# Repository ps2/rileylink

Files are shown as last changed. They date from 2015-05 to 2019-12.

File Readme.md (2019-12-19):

# RileyLink



A custom designed Bluetooth Smart (BLE) to Sub-1 GHz module. It can be used to bridge any BLE capable smartphone to the world of Sub-1 GHz devices. 

### Setup

 * There is a [FAQ](https://docs.google.com/document/d/1-KlewmRObpUWCTQSq9EPraN8R-6rCksJS_sRSQSexX0/edit#) covering some questions about installing the firmware.
 * [@loudnate](https://github.com/loudnate) recorded a [setup log](https://docs.google.com/document/d/1-bGBXbxVKOs_tDXi68qiOD7bIT6tQlkQydXn5Q-afLc/edit) of his experience.

### Hardware

See the [hardware](https://github.com/ps2/rileylink/tree/master/hardware) directory for design files to build a RileyLink. The hardware design is released under [Creative Commons Share-alike 3.0](http://creativecommons.org/licenses/by-sa/3.0/).  This board has small parts and will need to be reflow soldered; using a solder-paste stencil is recommended. 

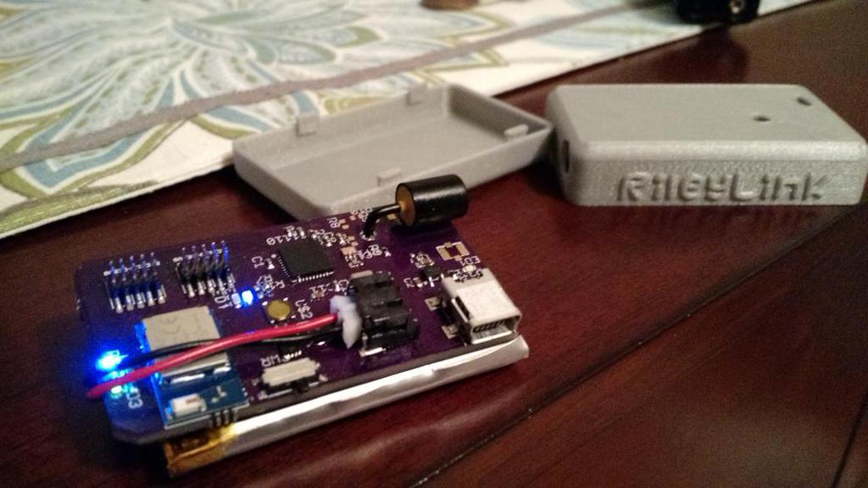
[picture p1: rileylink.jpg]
RileyLink Hardware


### Order a Pre-Assembed RileyLink
From time-to-time community members do a production run of pre-assembled RileyLink Boards. When they are available you can place an order here [GetRileyLink](https://getrileylink.org/)

### Firmware

The code in the [firmware](https://github.com/ps2/rileylink/tree/master/firmware) directory runs on the RileyLink hardware.  There are two main chips on the RileyLink, and thus two firmware images.

### LED Lights

There are blue and green leds near both chips. The ble113 is on the upper right of the board, and the cc1110 is in the lower middle.  

Blue for the ble113 indicates there are packets received and ready for a phone to pick up. Green means the phone is connected to the ble113.

On the cc1110, I blue is a timer based on/off, letting you know the firmware code is running. Green is toggled when a packet comes in.

The other red LED indicates charging.

### License

The MIT License (MIT)

Copyright (c) 2015 Pete Schwamb

Permission is hereby granted, free of charge, to any person obtaining a copy
of this software and associated documentation files (the "Software"), to deal
in the Software without restriction, including without limitation the rights
to use, copy, modify, merge, publish, distribute, sublicense, and/or sell
copies of the Software, and to permit persons to whom the Software is
furnished to do so, subject to the following conditions:

The above copyright notice and this permission notice shall be included in all
copies or substantial portions of the Software.

THE SOFTWARE IS PROVIDED "AS IS", WITHOUT WARRANTY OF ANY KIND, EXPRESS OR
IMPLIED, INCLUDING BUT NOT LIMITED TO THE WARRANTIES OF MERCHANTABILITY,
FITNESS FOR A PARTICULAR PURPOSE AND NONINFRINGEMENT. IN NO EVENT SHALL THE
AUTHORS OR COPYRIGHT HOLDERS BE LIABLE FOR ANY CLAIM, DAMAGES OR OTHER
LIABILITY, WHETHER IN AN ACTION OF CONTRACT, TORT OR OTHERWISE, ARISING FROM,
OUT OF OR IN CONNECTION WITH THE SOFTWARE OR THE USE OR OTHER DEALINGS IN THE
SOFTWARE.

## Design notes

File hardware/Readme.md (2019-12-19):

# RileyLink Hardware

 * board.sch - circuit schematic
 * board.brd - pcb design file
 * bom.csv - materials list
 * case_bottom.stl - 3d printer model for case bottom
 * case_top.stl - 3d printer model for case top

### Order the PCB from OSH Park:

[RileyLink v1.0](https://oshpark.com/shared_projects/jWrg6WmU)

### Components

The bom.csv file contains a list of parts and quantities along with their Digikey part number.

### PCB Assembly

A stencil for the PCB can be obtained at a reasonable price from [OSH Stencils](https://www.oshstencils.com).  Just upload the .brd file and accept the default mappings.

You will have to look at the schematic and the PCB PDFs or open them in [Eagle](http://www.cadsoftusa.com/) to know where the parts go, and how they are oriented.

I use a hot-air rework station to flow the solder paste, but you could use a toaster oven setup as well.

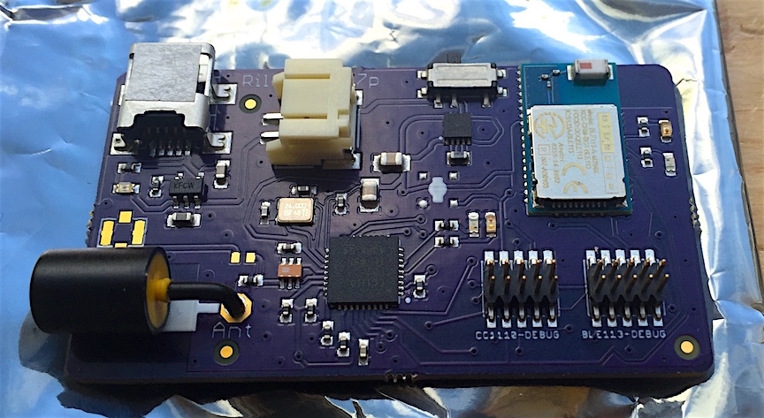
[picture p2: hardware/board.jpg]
Assembled Board


### Case

I created a case using [Tinkercad](https://www.tinkercad.com), a great tool.

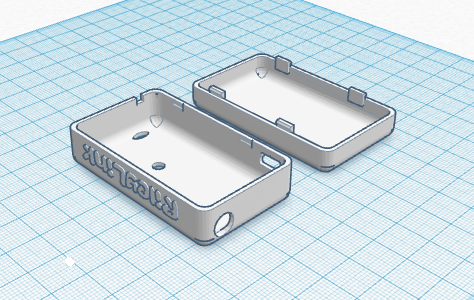
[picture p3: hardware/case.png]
3D Printed Case


The case is designed to hold an [850mAh Lipo](https://getrileylink.org/product/850lionbattery/). That battery lasts a day or so when the RileyLink is constant listen mode. It should last longer if the firmware uses a duty cycle that's less than 100%.

### Fitting components inside case

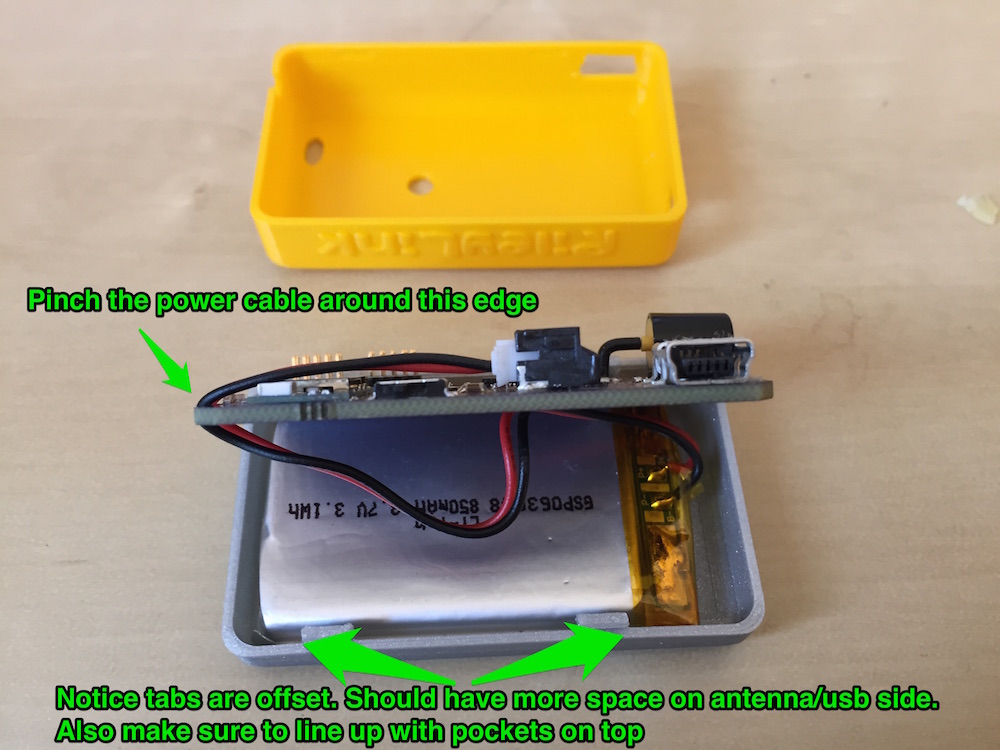
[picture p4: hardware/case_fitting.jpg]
Case Fitting


Note: there’s an issue I have with the case that I haven’t fixed yet; the board in the case can rotate a bit so that the usb port doesn’t line up with the hole. If stick a small something (like those sticky pads that keep cabinet doors from slamming) to the top of the usb port, that fixes the issue.

### 868MHz (EU) version

Since the firmware allows changing of the frequency, and most people are using the 915Mhz antenna successfully with 868Mhz pumps, a custom RileyLink is not needed.

### License

The hardware design is released under [Creative Commons Share-alike 3.0](http://creativecommons.org/licenses/by-sa/3.0/).

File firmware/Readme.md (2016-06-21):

# Loading Firmware

There are two microprocessors on the RileyLink board; a ble113 module, and a cc1110. Each needs it's own firmware.

## CC1110 Firmware

For the cc1110, you should install the latest [subg_rfspy](https://github.com/ps2/subg_rfspy) firmware.

- Use spi1_alt2_RILEYLINK_US_STDLOC.hex if you are in the USA/Australasia
- Use spi1_alt2_RILEYLINK_WW_STDLOC.hex if you are elsewhere (the pump serial printed
    on the back of the device will end with 'WW' if you need to use this)

## BLE113 Bluetooth Module

For the ble113, you should install the firmware in the ble113_rfspy subdirectory.
Using the BLE Update tool (details below).

1. Install the Bluetooth Firmware Update and the Bluetooth SDK tools as per the "Prerequisites" section below.
2. Install SmartRF Studio as below, so that you have USB drivers for the CC-Debugger.
3. Go to https://github.com/ps2/rileylink and click the "Clone or download" option.
4. Select "Download ZIP"
5. Extract the Zip in your download directory.
6. Double click on the Project file in the ble113_rfspy folder.
7. If you receive the message "Unable to automatically select BGBuild":
  - Click BGBuild menu item, and choose "Manually Select"
  - Choose My Computer -> C: -> Bluegiga -> blue-1.4.2-130 (or similar) -> bin -> bgbuild

## Disabling Bluetooth

If you want to completely disable the bluetooth part of the RileyLink, you can use the
'ble113_disabled' firmware. This is normally only done when you are using the RileyLink
over serial, using it as a mmeowlink radio.

## Prerequisites

## CC1110 Firmware

If you can, use a pre-built firmware from subg_rfspy release list on GitHub. You can then
use the following tools to write the firmware:

* For Windows: [cc-debugger](http://www.ti.com/tool/cc-debugger)
* For Linux: cc-tool. See [cc-tool](https://github.com/oskarpearson/mmeowlink/wiki/Firmware-install-with-CC-Tool-%28Linux%29) for instructions on installation and usage.

### Bluetooth Firmware

Windows machine (or VM) with:

* SmartRF Studio - tested with 2.3.1 from http://www.ti.com/tool/smartrftm-studio (Make sure to 'Extract All' if prompted at install/unzip time)
* "BLE Update Tool v1.3.6 (Windows XP,7,8 and 10)" (or above) **AND** "Bluetooth Smart Software and SDK v.1.4.2" applications
from the [ble113 product page](https://www.bluegiga.com/en-US/products/software-bluegiga-bluetooth-smart/)

Note that you will need to sign up for an accounts to download both installers.

## Troubleshooting

- If you receive the message "CebalChip Object has no attribute Reset" when writing
  bluetooth firmware, then check that you've not accidentally plugged into the
  CC1110 port. Also check that you've connected the CC-Debugger correctly.

## Connecting the CC Debugger to the RileyLink

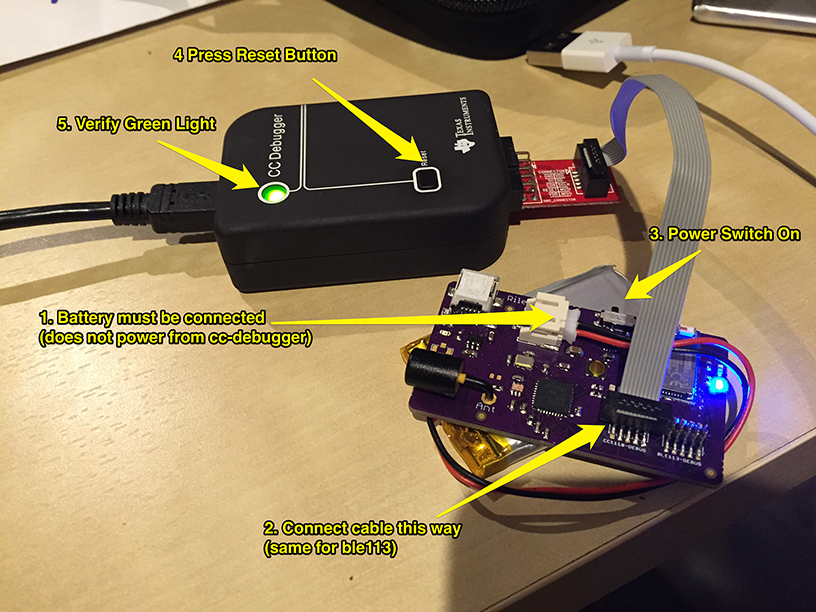
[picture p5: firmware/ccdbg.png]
cc-debugger connection illustration


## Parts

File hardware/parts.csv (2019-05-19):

Part | Description | Digi-Key Part Number
ANT1 | Antenna 916MHZ | ANT-916-JJB-RA-ND
BLE113-DEBUG | CC-Debugger Header | 609-3695-1-ND
C1 | 0.10µF ±10% 10V X5R Capacitor 0402 | 587-1227-1-ND
C2 | 4.7µF ±10% 10V X5R Capacitor 0603 | 445-7482-1-ND
C3 | 4.7µF ±10% 10V X5R Capacitor 0603 | 445-7482-1-ND
C4 | 10µF ±10% 6.3V X5R Capacitor 0805 | 1276-6457-1-ND
C5 | 12pF ±1% 50V C0G, NP0 Capacitor 0402 | 490-6196-1-ND
C6 | 12pF ±1% 50V C0G, NP0 Capacitor 0402 | 490-6196-1-ND
C7 | 0.10µF ±10% 10V X5R Capacitor 0402 | 587-1227-1-ND
C8 | 0.10µF ±10% 10V X5R Capacitor 0402 | 587-1227-1-ND
C9 | 1µF ±10% 6.3V X5R Capacitor 0402 | 399-4873-1-ND
C10 | 0.10µF ±10% 10V X5R Capacitor 0402 | 587-1227-1-ND
C11 | 10µF ±10% 6.3V X5R Capacitor 0805 | 1276-6457-1-ND
C12 | 0.10µF ±10% 10V X5R Capacitor 0402 | 587-1227-1-ND
C13 | 0.10µF ±10% 10V X5R Capacitor 0402 | 587-1227-1-ND
C14 | 4.7µF ±10% 10V X5R Capacitor 0603 | 445-7482-1-ND
CC1110 | CC1110 SOC RF Transceiver | 296-38560-1-ND
CC1110-DEBUG | CC-Debugger Header | 609-3695-1-ND
IC1 | 915 MHz Impedance Matched Balun-Filter | 712-1541-1-ND
JP1 | 2 Positions JST Header 2mm | 455-1749-1-ND
L1 | 2.2µH Shielded Wirewound Inductor 1.46A | SRN3010-2R2MCT-ND
LED1 | LED RED CLEAR 0603 SMD | 160-1447-1-ND
LED2 | LED BLUE 0603 SMD | 350-4381-1-ND
LED3 | LED GREEN CLEAR 0603 SMD | 511-1299-1-ND
LED4 | LED GREEN CLEAR 0603 SMD | 511-1299-1-ND
LED5 | LED BLUE 0603 SMD | 350-4381-1-ND
PWR | SWITCH SLIDE SPDT 300MA 6V | 401-2016-1-ND
R1 | 2k Ohm ±5% 0.063W, 1/16W Resistor 0402 | 311-2.0KJRCT-ND
R2 | 330 Ohm ±5% 0.063W, 1/16W Resistor 0402 | 311-330JRCT-ND
R3 | 56k Ohm ±1% 0.063W, 1/16W Resistor 0402 | 311-56.0KLRCT-ND
R7 | 470 Ohm ±1% 0.063W, 1/16W Resistor 0402 | 311-470LRCT-ND
R9 | 0.0 Ohm Jumper 0.063W, 1/16W Resistor 0402 | 311-0.0JRCT-ND
R11 | 470 Ohm ±1% 0.063W, 1/16W Resistor 0402 | 311-470LRCT-ND
R12 | 470 Ohm ±1% 0.063W, 1/16W Resistor 0402 | 311-470LRCT-ND
R13 | 470 Ohm ±1% 0.063W, 1/16W Resistor 0402 | 311-470LRCT-ND
U1 | L-ION Battery Management IC | MCP73831T-2DCI/OTCT-ND
VREG | 3.3V Buck Converter 0.6A SOT23 | LM3671MF-3.3/NOPBCT-ND
U3 | Bluetooth Low Energy BLE113-A 256K | 1446-1035-1-ND
X1 | 24MHz ±15ppm Crystal 8pF 50 Ohm | 644-1052-1-ND
X3 | USB - mini B USB 2.0 Receptacle Connector | H2959CT-ND

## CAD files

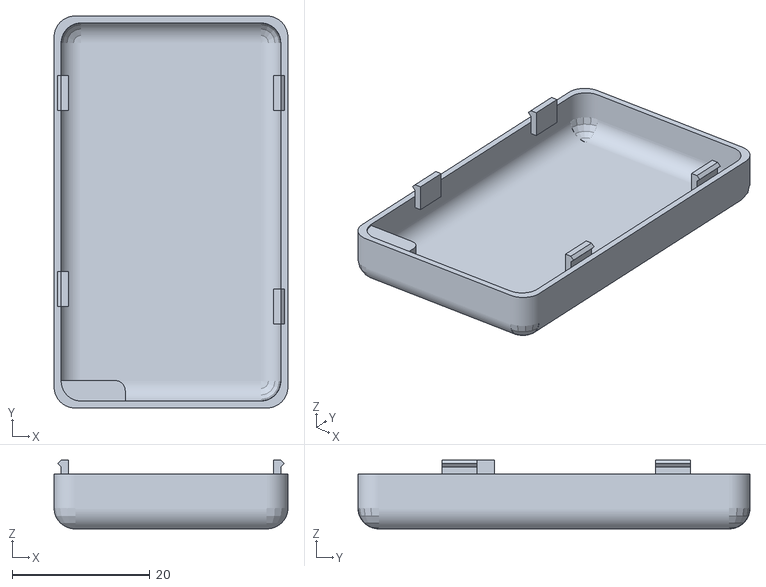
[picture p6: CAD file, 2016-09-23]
hardware/case_bottom_edit.stl
34.0 x 57.0 x 10.0

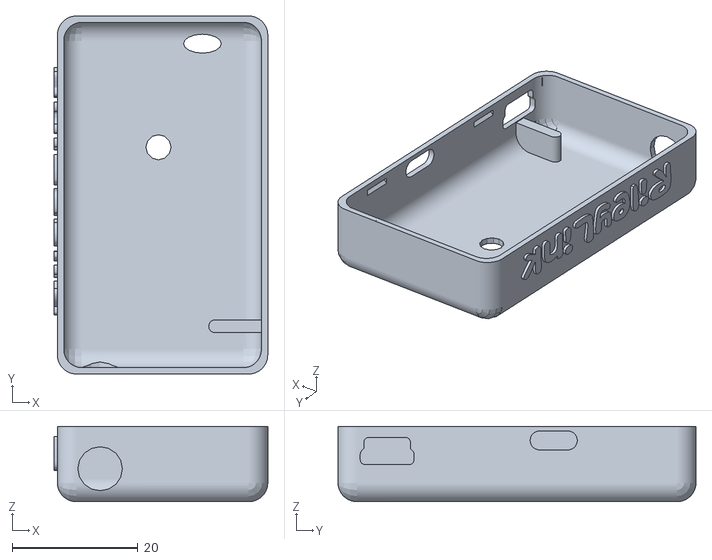
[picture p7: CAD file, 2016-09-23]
hardware/case_top_edit.stl
34.0 x 57.0 x 12.0

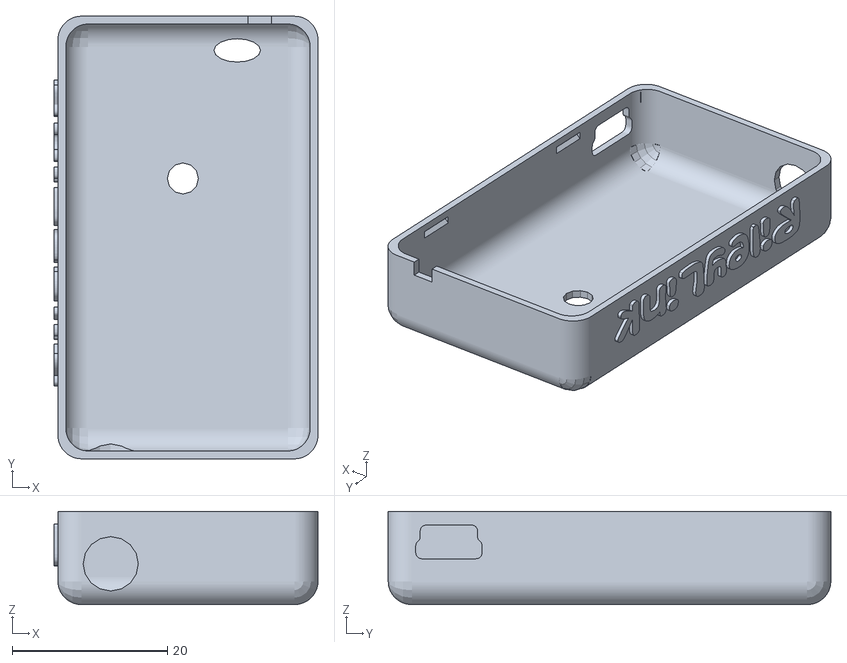
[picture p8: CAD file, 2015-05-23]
hardware/case_top.stl
34.0 x 57.0 x 12.0

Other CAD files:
hardware/case_bottom.stl

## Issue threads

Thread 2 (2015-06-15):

bigger ble pads

ps2, 2015-06-15:
bluetooth board part in eagle needs to be a bit bigger. Extend the pads out a little. Probably 1mm on the left and right side. This will allow hand soldering and better smt soldering with no bubbles

ps2, 2016-07-26:
after having RL's produced at professional shops with no issues here, I think we'll leave them as is.

Closed 2016-07-26.

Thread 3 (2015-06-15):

update switch

ps2, 2015-06-15:
Switch should be fixed also it's a little off.

ps2, 2015-08-23:
I'm not sure exactly what this refers to. Jason made a comment, and I recorded this ticket, but afaik, the switch works fine.

Closed 2015-08-23.

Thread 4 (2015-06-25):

add bluetooth device serial # to guarantee binding to unique device.

ps2, 2015-06-25:

ps2, 2015-08-17:
The app now remembers bluetooth device ids, and lets the user specify which ones to connect to.

Closed 2015-08-17.

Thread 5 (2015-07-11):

button

AtomSoftTech, 2015-07-11:
Remove reset

Closed 2017-03-10.

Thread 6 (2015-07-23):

app: feature to configure pump as mysentry broadcast (pair)

ps2, 2015-07-23:
MySentry has the user put the pump into a discovery mode, where it broadcasts packets including the pump id.  The MySentry sends a response with its own id, which the pump then adds to its list of devices it accepts queries from. The pump also then starts broadcasting pump status messages every five minutes.

The screen should walk the user through this process, using a paired RileyLink, and display status updates as it receives packets from the pump and verifies it can talk to the pump.

loudnate, 2015-07-23:
Have you captured the packet that needs to be sent back?

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

ps2, 2015-07-23:
I believe the packets involved have these types:

https://github.com/ps2/minimed_rf/blob/master/lib/minimed_rf/messages/message_type_map.rb#L10-L11

I'll see if I can find full examples in my packet log.

ps2, 2015-07-23:
It looks like this:

a2 AAAAAA 0a BB CCCCCC DD EE

AAAAAA = pump id
BB = ? (my example had 8f)
CCCCCC = mysentry id (mine was 000695)
DD = ? (my example had 01)
EE = crc

loudnate, 2015-07-30:
Will the RileyLink capture the pump's broadcast packets during discovery mode? I lack a lot of understanding in how the actual IC Rx/Tx flows work, but I'm eager to figure this out.

ps2, 2015-07-30:
Yes, the Rileylink will listen for the pump's message, since it has the pump ID in it, and that way the user doesn't have to enter it in.

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

loudnate, 2015-08-10:
Have you started this feature? I can take a stab at it this week since I'm going to have to go through this process anyway with my rig.

ps2, 2015-08-10:
I haven't started it quite yet; I am working on the packet sending code, so this particular area is in a bit of flux. I think I'm close, though.  Feel free to start if you want; just be warned that the sending code in RileyLinkBLEDevice is changing.

loudnate, 2015-08-12:
What's the significance of "0a" in the MySentry discovery confirmation packet?

Here's the packet format sent by the pump in "Find Device" mode:
`a2 594040 09 BB 999999 00 EE`

BB increments, usually as a single counter, which keeps the CRC (EE) changing, but the byte prior is always 09. Does 09 signify a discovery while 0a signifies a confirmation?

ps2, 2015-08-12:
That's my take on it as well: https://github.com/ps2/minimed_rf/blob/master/lib/minimed_rf/messages/message_type_map.rb#L10-L11

loudnate, 2015-08-12:
I played with this for a bit but didn't have any luck pairing yet. Any idea on the frequency and repetitiveness of the link messages?

The `BB` sequence in the pump message is a counter that increments by 1, though it sometimes repeats in the same second. It's not time-based, though: if you exit the Find Device mode and start over, it will pick up where it left off. I wonder if it needs to be replayed in the link message?

loudnate, 2015-08-14:
From @ps2: https://gist.github.com/ps2/f80ff7a400bcecfd9479

loudnate, 2015-08-14:
Here's what worked for me:
```objc
@interface MySentryPairingViewController () {
    unsigned char _messageCounter;
}

- (void)viewDidLoad {
    [super viewDidLoad];
    [self.device setTXChannel:3];
    _messageCounter = 0;
}

- (NSString *)mySentryReplyForPacket:(MinimedPacket *)p
{
    static NSString *MySentryID = @"000888";

    NSString *packetStr = [@"a2" stringByAppendingFormat:@"%@%02x%02x%@00%02x000000",
                           [[Config sharedInstance] pumpID],
                           MESSAGE_TYPE_PUMP_STATUS_ACK,
                           messageCounter++,
                           MySentryID,
                           p.messageType];

    return packetStr;
}
```

It's possible to replay multiple messageTypes in a single `06` packet, and @ps2's paring log shows this, but I simply replied immediately during my spoofing.

Closed 2015-08-15.

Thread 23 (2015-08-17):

Send ACK for all `a2` packets

loudnate, 2015-08-17:
Should we keep track of paired MySentry IDs, then?

loudnate, 2015-08-17:
Pete suggested we don't have to worry about "real" MySentry devices, and of course we'd only ACK for the Pump IDs we know about.

ps2, 2015-08-18:
This issue was moved to ps2/rileylink_ios#2

Closed 2015-08-18.

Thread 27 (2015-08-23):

unique id

ps2, 2015-08-23:
Expose a unique id as an attribute, based off of the internal unique bluetooth id.

https://bluegiga.zendesk.com/entries/72030216--HOW-TO-Get-a-BLE-peripheral-MAC-address-with-iOS-and-CoreBluetooth

This id can be used for traceability, to determine what happened after issues occur.

Closed 2017-03-10.

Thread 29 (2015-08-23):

semver for cc1110 firmware

ps2, 2015-08-23:
This should also be made visible as a bluetooth attribute

ehwest, 2016-01-23:
Can you please document somewhere exactly how the RF modem used for the Nightscout project relates to the cc1110 firmware properties?  How did you select the requisite header file values?

ps2, 2016-01-23:
Not sure what you're asking here.  This ticket is about letting users know which version of firmware they currently have installed on their device.

The gitter channel (https://gitter.im/ps2/rileylink) is a good place to ask general questions about this project.

ps2, 2016-07-26:
We have firmware version reporting from subg_rfspy now.

Closed 2016-07-26.

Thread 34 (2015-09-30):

Mouser Project for UK/UE Rileylink

oskarpearson, 2015-09-30:
Hi

Attached is a Mouser project with enough components to make about 5 UK/EU Rilelylinks with a bunch of the cheap components spare (enough to lose / burn out / keep for later)

Note - it will _not_ work in the USA as I've changed the Balun and Antenna as described at https://github.com/ps2/rileylink/tree/master/hardware#868mhz-eu-version

I'm not 100% sure the components are all correct yet - but if they are, it should ease ordering for other people, since they don't have to select from 27,000+ capacitor models.. Feedback on my selections is welcome. My one concern is it seems some of the capacitors in the diagram are electrolytic - but I couldn't find electrolytic capacitors in those ranges. I also had to switch the LEDs, as I couldn't find the model referenced.

http://www.mouser.com/ProjectManager/ProjectDetail.aspx?AccessID=2316caefe4

Once I know this works, I'll submit a PR and update the BOM

Oskar

ps2, 2015-09-30:
Thanks Oskar!

I built a list at digikey using the same components that I've used to build my own RileyLinks.  Might want to compare the capacitors and resistors.  There are only a few that require tight tolerances.  The led resistors and power filtering caps just have to be ballpark.

https://www.digikey.com/classic/RegisteredUser/BOMBillOfMaterials.aspx?path=1&exist=1&id=2957565

This list also has "extra" parts for the 0402 size pieces, as those are super easy to lose.  Sometimes the extra amount is 10+, since it's cheaper to buy 10 than it is to buy 2 or 3.

Closed 2017-03-10.

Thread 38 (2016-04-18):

Use pump TZ instead of local TZ for parsing events.

ps2, 2016-04-18:
Primary issues in NightscoutUploadKit

loudnate, 2016-04-18:
There's a couple of interesting things here.

1. History parsing always needs to start from page 0 so no time change events are missed.
2. More than one time change record can occur during a pass-through history, so there's a concept of a mutable time zone during the reverse-walk.

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

Closed 2017-03-10.

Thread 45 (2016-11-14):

Provide battery voltage

trixing, 2016-11-14:
It would be great to have a way to ask rileylink for the voltage of the internal battery to alert users when it needs to be charged.  Not sure if that's possible with the current hardware or would need some changes?

trixing, 2017-01-13:
Most notable  P0_7 - P0_0 are connected to the ADC, so a voltage divider of VBAT to any of these would do the trick.

ps2, 2017-01-13:
Yes, I've looked at doing a vdiv, but decided that would be constantly draining power (though I haven't done the work to figure out how low I can make that leak and still measure accurately).

So I designed a version that used a mosfet to turn on and off a vdiv measuring circuit, but I had issues with my prototypes (must've screwed up something). At that point I decided I'd sunk too much energy into the issue.

For me, the main goal here is to minimize the effort users have to spend on maintaining charge on the RL.  Nightly charging is the simplest method, in my opinion.  I'd rather have a habit that I don't think about than have to look at battery status routinely. I'd even take a nightly charge over a 4 or five day charge.

Back when android phones had way worse battery life than iPhones (they've both moved in directions that make them more comparable now), I had an android and my wife had an iPhone.  I was forced into nightly charging, whereas she could go several days w/o charge.  Guess who had more annoying impacts due to running out of power at inconvenient times?

So, this issue has been thought through (maybe too much).  As usual, I'd love PRs that are a result of tested prototypes.  Otherwise this kind of report is usually just idle speculation from a back-seat designer. ;)

trixing, 2017-01-13:
Typically you would use a 10k / 10k Ohm divisor, which would put current at 3.7V / 20000 = 0.185mA.  Given that this is a 850mAh battery it would only affect the battery life very minimally.

Do you actually know what is drawing so much power to drain the 850 mAh that quickly?

ps2, 2017-01-13:
Yes, I think my original idea to save power with a mosfet was probably overkill, but after spending all that time on it, and realizing that it wouldn't make much of a difference in my use of the device, I decided not to spend more time chasing after it. Again, feel free to work on an updated design, test it, and submit a PR.  As in software, idle comments on how things can be improved without actual contribution can be irritating to the people that work through all the details of actual implementation.  In hardware it's even worse, as the cycles are so long.

Regarding your second comment, are you referring to the regulator issue?  If so, please move that comment over there.

Closed 2017-01-13.

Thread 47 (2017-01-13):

The voltage converter design should follow recommendations from the datasheet

trixing, 2017-01-13:
http://www.ti.com/lit/ds/symlink/tps63031.pdf #11.2

in particular the placement of the capacitors could be better.

Also I wonder how the induction coil was chosen?  It seems to be 7x the internal resistance than the recommended types in the datasheet (0.7 Ohm vs. 0.1 Ohm or less).

(I have a problem with the tps chip getting really hot, but still keeping voltage - I'm theorizing there is some stray capacitance/inductance with some bad feedback. Everything else works.)

ps2, 2017-01-13:
I've gone through several versions of the design that follow the datasheet layout and component selection more closely, and have still been having issues.

Check out the https://github.com/ps2/rileylink/tree/v1.0t branch, for the latest.

ps2, 2017-01-13:
Actually, the v1.0t is using a completely different regulator.  Check out v0.8test2 for previous versions that use the same regulator but follow the datasheet very strictly.

trixing, 2017-01-13:
I'm surprised that still causes issues - what kind of issues if I might ask?  Did you consider just using a 3.3V LDO?

ps2, 2017-01-13:
Same issues of overheating, drawing 200mA.  Yes, looked at 3.3V ldo; wanted a more efficient design, so the new one is a buck.

trixing, 2017-01-26:
I just tried this.  I have a Rileylink which pulls 300mA from the Lipo constantly.  To test if the regulator is broken I directly connecting 3.3V _after_ the regulator.  This lead to a power draw of 0.02A and a working communication with the pump.

Next step I put in a LM1117-3.3V (bad choice but the only one I had around, drop-out of 1V, thus 3.1V at the CC1110).  With a voltage of 5V applied at the input side my current draw is also only 0.02A.  The efficiency seems to be similar and the Rileylink is working again.

I have to get a LDO with less drop-out voltage, otherwise I can only get around 20-30% capacity out of the battery.  Luckily there is a bunch of alternatives and I just ordered an LP2992 which supposedly only has around 0.1V drop voltage.

(As background I can recommend reading

http://electronics.stackexchange.com/questions/38782/regulated-3-3v-from-a-lithium-ion-or-lipo-battery )

Closed 2017-03-10.

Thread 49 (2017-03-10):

Power failure

jessicakarma, 2017-03-10:
Hi, I've using RileyLink and Loop since 1/20/2017.  In the past few days Loop has not been connecting (indicated by red circle) and I realized that RileyLink is not holding a charge.  Starting today it doesn't appear to be working at all, even when plugged in.

I saw there is an update coming.  Question:  Do I need to buy another one, or will a replacement be sent automatically?  If I buy another, of course I'd like to have the new version.

Thanks!

ps2, 2017-03-10:
The green light is not a power light. It's a bluetooth connection light. Have you tried diagnosing your bluetooth connection?  Try restarting the Loop app, and bluetooth on the phone, and see if the green light comes on.

Also, check your battery connector to make sure it's seated all the way in (on some rileylinks this can be a very tight fit).

jessicakarma, 2017-03-10:
Hi Pete, thanks much for your quick reply!

I’ve been restarting both the Loop app and the phone; sometimes this works but unfortunately not today.  Other bluetooth devices continue to work including Dexcom G5, so I take it the issue is with the RileyLink connection?

I also opened RileyLink and set the battery and connector i proper place.  Al components are sung and seem to be where intended.

Any other suggestions?

Love Loop, and a big part of that is the streamlined equipment made possible by you!  Many, many thanks for this!! :-)

Take care,
Jessica

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

ps2, 2017-03-10:
Send me a DM on gitter or facebook, and I'll see if we can get you a replacement.

Closed 2017-03-10.

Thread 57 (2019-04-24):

Parts list

javaboyjunior, 2019-04-24:
Hi there

4 of the parts in bom.csv are obsolete on Digikey.com. I have been in touch with Digikey and they have provided part numbers for replacement products. Will you accept a pull request for an updated bom.csv and confirm the specs of the 4 new parts if I make the edit?

Thanks

Mike

xs10shl, 2019-04-30:
Second the request. I'm getting the same Digi-Key errors, and would like to piggyback on the homework already done by javaboyjunior.

Also, If there's an alternate part number for the Omnipod antenna, perhaps that could be added as well. I see a few choices for the 433mhz antenna, none of which look exactly ghe same as the version you used.  ANT-433-HESM-ND appears to be the closest.

javaboyjunior, 2019-04-30:
Here's my list including replacement parts as recommended by Digikey Tech Support.

[bomupdatedmike.csv.zip](https://github.com/ps2/rileylink/files/3130036/bomupdatedmike.csv.zip)

xs10shl, 2019-04-30:
Thx much, I'll put eyes on it tomorrow as well.

stephenclong, 2019-05-19:
The parts list looks like it's specific to the Medtronic version?  Can someone who knows way more about this than me provide details of which parts I need to switch out to make it work for the Omnipod?  Is it the same PCB?

javaboyjunior, 2019-05-19:
I asked in the support channel and was told the Parts are the same other
than the antenna. I used this for the antenna...

DAOKI 10pcs 433MHz antenna...
https://www.amazon.com/dp/B01CGMOYYM?ref=ppx_pop_mob_ap_share

On Sat, May 18, 2019 at 8:59 PM stephenclong <notifications@github.com>
wrote:

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

ps2, 2019-05-19:
Yes the parts on the 433 MHz RL right now are the same as 915 MHz.  But we use this antenna: https://www.ebay.com/itm/10Pcs-433MHz-Helical-antenna-High-quality-Useful-with-Good-Quality/323119548775

ps2, 2019-05-19:
Looked over your replacements, and they look good @javaboyjunior. Thanks!

Closed 2019-05-19.

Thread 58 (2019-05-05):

R9 - where is it?

javaboyjunior, 2019-05-05:
I can find R9 on the PCB, silk screen or in Eagle but it is on the parts list. What am I missing? Thanks!

javaboyjunior, 2019-05-08:
Thanks!

Closed 2019-05-08.

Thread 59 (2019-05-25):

Now I have found R9...

javaboyjunior, 2019-05-25:
I see R4 is right above it but not listed in the parts list. I am building a 433Mhz board. Anything to be done here? Thank you

ps2, 2019-05-25:
R4 is just a place to put a 0-ohm resistor if you want to hook up the u.fl connector.

javaboyjunior, 2019-05-25:
Thank you

On Sat, May 25, 2019 at 3:17 PM Pete Schwamb <notifications@github.com>
wrote:

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

Closed 2019-05-25.

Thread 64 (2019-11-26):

Antenna 433MHz for omnipod rileylink in parts list

jbayart, 2019-11-26:
For the omnipod rileylink, it is a 433 MHz antenna but there is no branch omnipod where the antenna is replaced in the csv in the hardware folder. I am not sure which antenna is used to build the riley.

breakery, 2019-11-26:
Not sure if I get your question right: still a simple helical antenna is used such as this one https://www.amazon.com/433MHz-Antenna-Control-Intercom-Helical/dp/B06Y691H5T

jbayart, 2019-11-26:
Yes I will probably use one like this. But I would like the exact same antenna like the other antenna with the digikey part number to be sure the dimensions fit with the case.

ps2, 2019-11-26:
There isn't a digikey part for this. These are the same part: https://www.ebay.com/itm/10Pcs-433MHz-Helical-antenna-High-quality-Useful-with-Good-Quality/323119548775

jbayart, 2019-11-26:
great, thanks !

larsvandoremalen, 2020-02-03:
Just to check, the ebay seller indicated does not ship to NL (almost nowhere in europe) and I read somewhere that the antenna signal quality has a lot of influence on creating screamers, would any of the digikey components below be good enough as well?

https://www.digikey.nl/product-detail/nl/pulselarsen-antennas/W3127/553-1696-ND/2538463
https://www.digikey.nl/product-detail/nl/linx-technologies-inc/ANT-433-HESM/ANT-433-HESM-ND/413457
https://www.digikey.nl/product-detail/nl/linx-technologies-inc/ANT-433-HETH/ANT-433-HETH-ND/625468

There is also an [aliexpress product](https://www.aliexpress.com/item/32962433768.html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,searchweb201602_4,searchweb201603_53) with a very low VSWR. But not certain if that makes it any better than the digikey ones.

First time posting, only just got started on building a loop. Want to do as much by myself as possible to fully understand the system. Thanks a lot for all the hard work that went into that!

breakery, 2020-02-04:
The aliexpress looks fine. Have a look here as well: https://www.amazon.de/dp/B00SO651VU/ref=cm_sw_em_r_mt_dp_U_N8roEb6AJERDF

Those are simple and tested. Range up to approx. 10m.

larsvandoremalen, 2020-02-05:
Thanks! Afraid even the amazon.de one does not ship to the Netherlands. They normally do but for components it's still a bit of hit and miss. Will try the aliexpress one then, thanks for the help.

breakery, 2020-02-05:
If urgent I can send one from de -> nl.

larsvandoremalen, 2020-02-05:
No urgency at all luckily, only preparing to start looping in March/April when I have everything ready. Good to now buy these components with some spare parts already :) Very nice of you to offer though, thanks!

breakery, 2020-02-05:
otherwise have a look here if you want to have some casing and inductive charging: https://sugarloop.makery.de/

ps2, 2020-02-05:
@breakery We have been testing out various designs of inductive charging, water resistant cases for the [official RileyLink site](https://getrileylink.org/), and we have one that is working *very* well; better than any of the others I've seen. It's going to be injection molded, so it's taking a little while to get the tooling set up.

Closed 2019-11-26.

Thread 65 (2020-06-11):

BOM for 433 Mhz version

konovagit, 2020-06-11:
Hi Pete,

I have a question concerning the 433 MHz version. Do you have a bom.csv for this version ?

OtherwiseI just have to change the antenna and the balun, right? I see this version https://getrileylink.org/product/rileylink433 so if you have the component ref it will be great.

Thank you for your job :)

jaredkzr, 2020-10-13:
I'm curious about this as well. The 433 MHz version purchased from https://getrileylink.org/product/rileylink433 appears to have the 915 MHz balun installed which would cause a reduction in range. I can't confirm this though since we have no BOM for the 433 MHz version.

It does appear that changing the antenna and balun is all that is necessary as far as the hardware is concerned. The CC1110 transceiver will have to be configured for 433 MHz though.

hansdampf01, 2020-10-22:
just found this issue: https://github.com/ps2/rileylink/issues/57 where the same question was asked and Im also facing it.
It seems like the antenna module of the 915mhz version will be need you just replace the actual antenna. e.g. to this:

https://www.amazon.de/gp/product/B07QGQ1VG5/ref=crt_ewc_title_huc_1?ie=UTF8&psc=1&smid=A3BN2T8LLIRB5S

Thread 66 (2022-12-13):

I have trouble with the rileylink

henrycoding, 2022-12-13:
Thank you very much for such open-source project. I'm going to follow your steps to make my own rileylink, but the pump doesn't respond in time. I'd like to debug the link between the CC1110 and my pump, but it seems the protocol of Medtronic 722 is not available on the Internet. So I wonder if there are some basic commands I can send to the pump to test the wireless link ?  Thanks a lot !!!

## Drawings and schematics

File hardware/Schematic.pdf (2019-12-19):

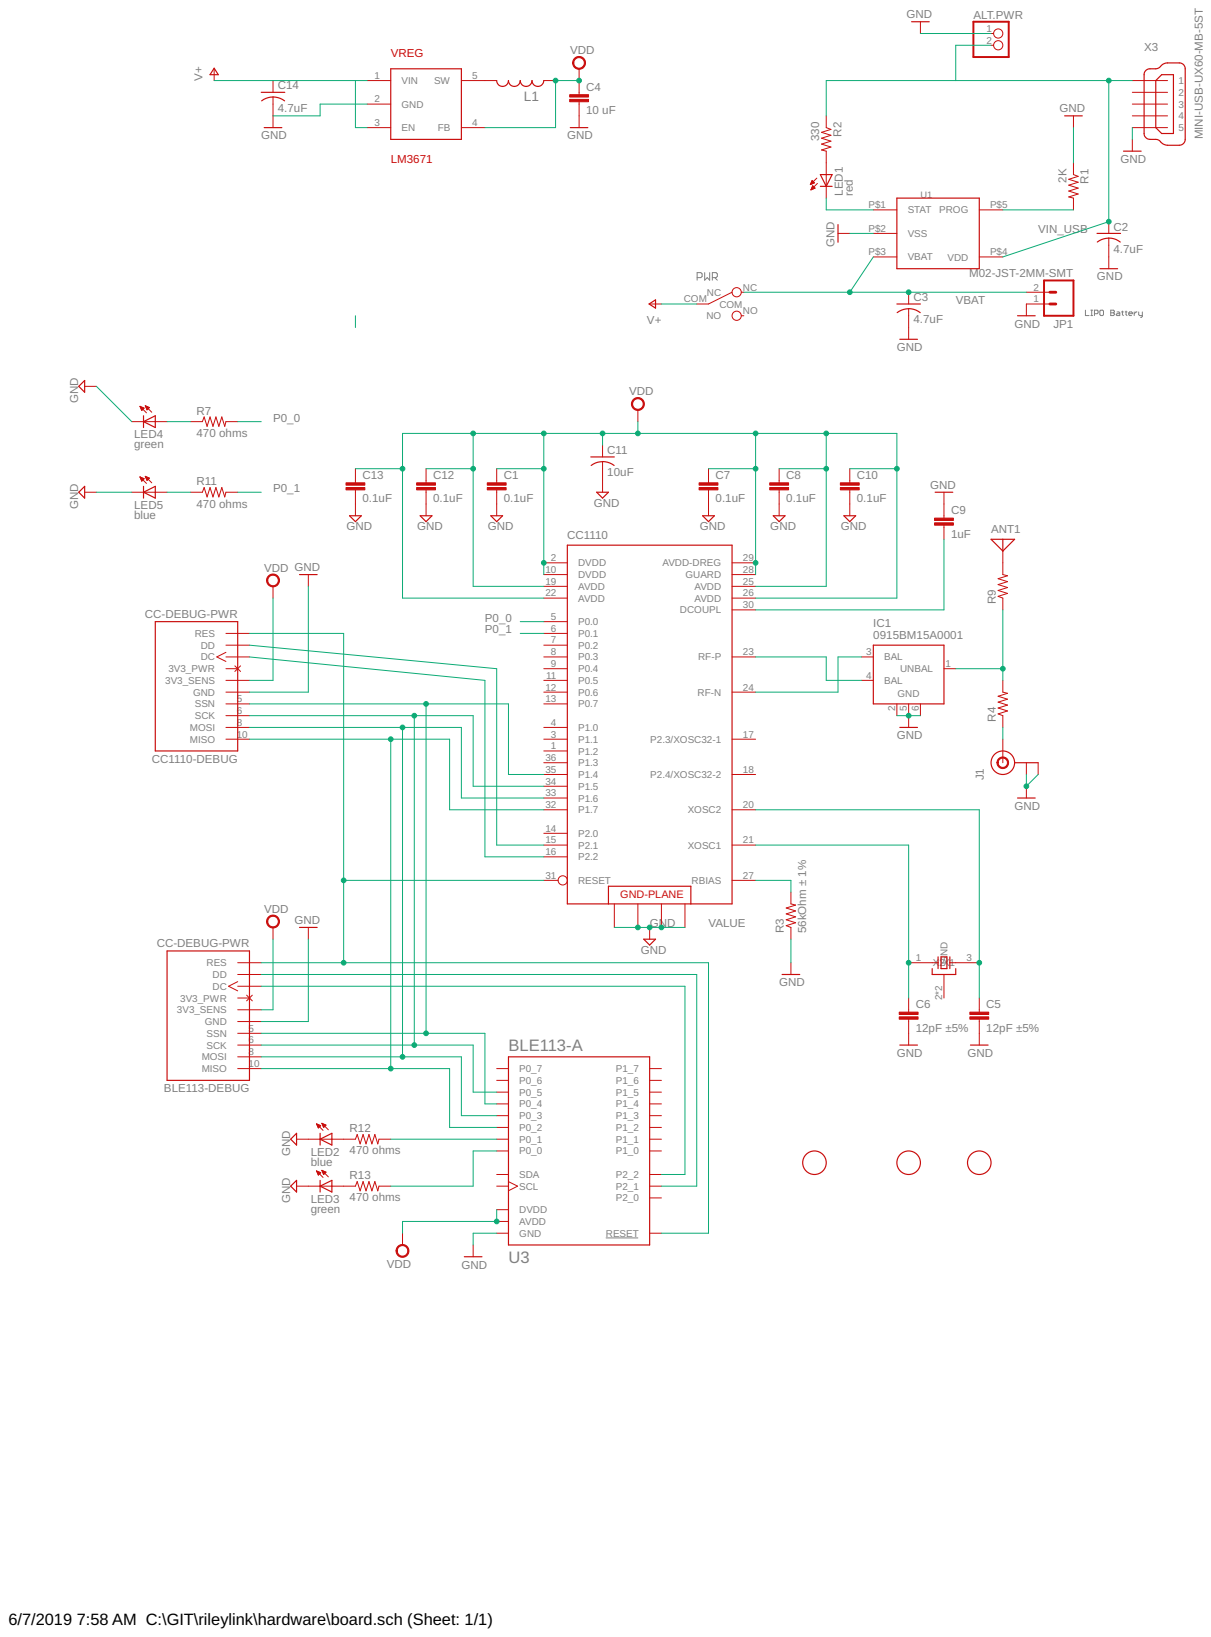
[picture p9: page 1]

6/7/2019 7:58 AM C:\GIT\rileylink\hardware\board.sch (Sheet: 1/1)

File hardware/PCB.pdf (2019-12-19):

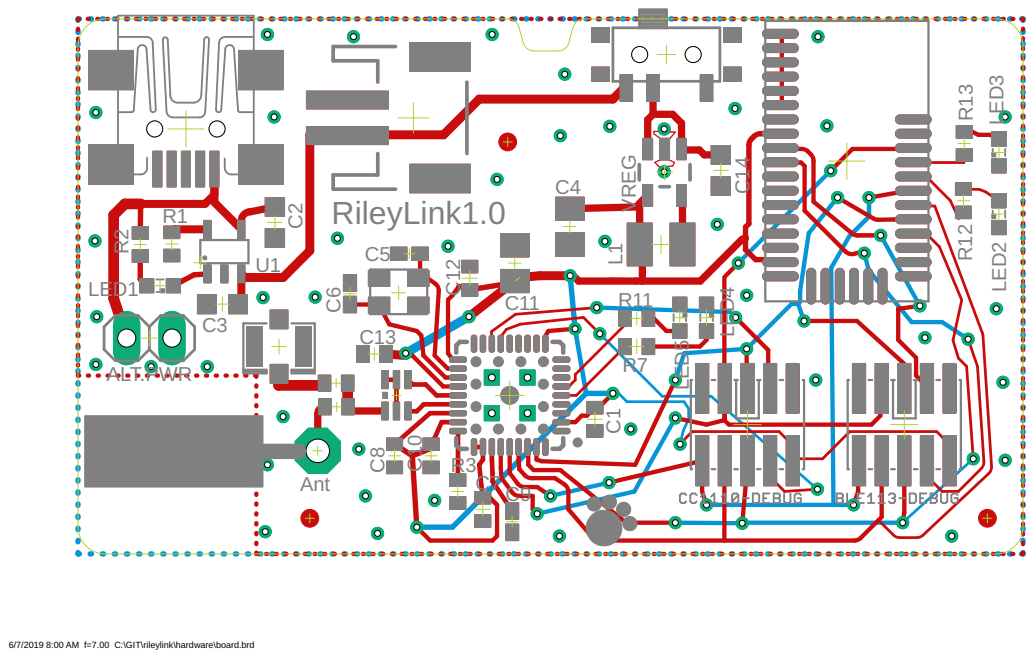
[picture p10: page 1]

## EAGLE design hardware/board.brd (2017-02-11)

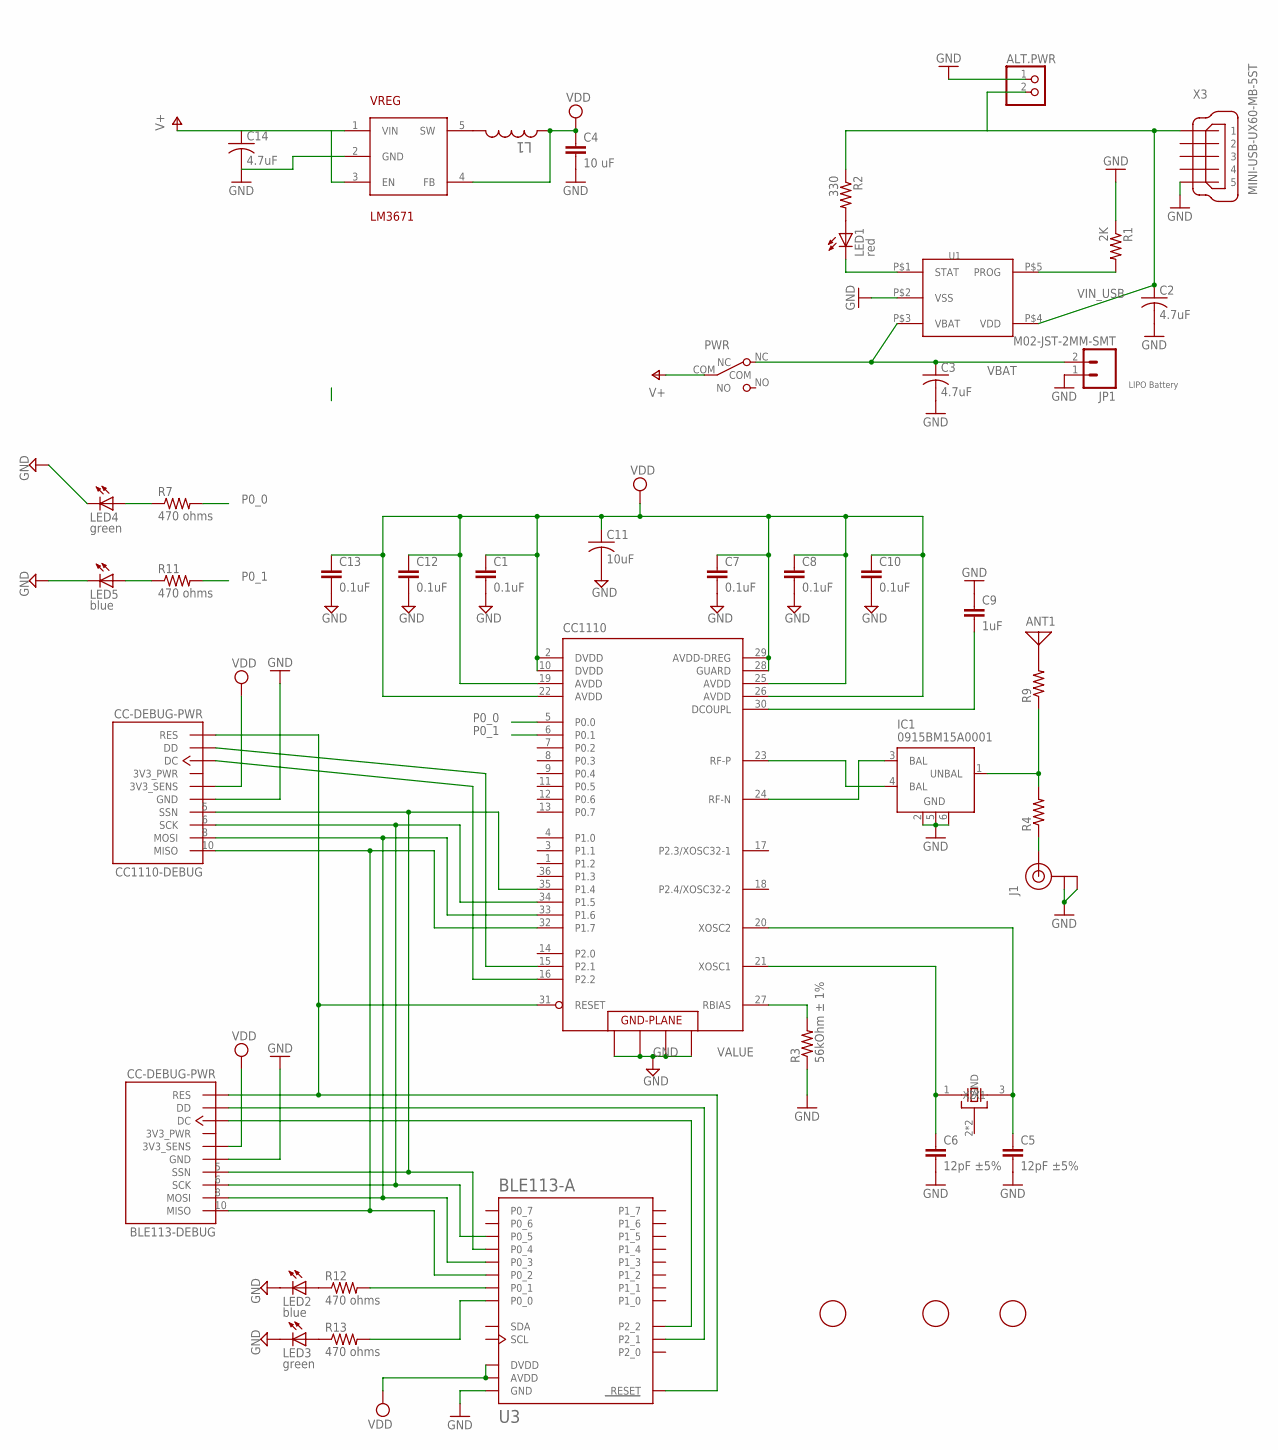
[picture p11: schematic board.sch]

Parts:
ALT.PWR: PINHD-1X2; 1X02
ANT1: ANTENNA; PAD-01
BLE113-DEBUG: CC-DEBUG-PWR; CC-P05
C1, C7, C8, C10, C12, C13: 0.1uF; C0402
C2, C3, C14: 4.7uF; C0603K
C4: 10 uF; C0805K
C5, C6: 12pF ±5%; C0402K
C9: 1uF; C0402K
C11: 10uF; C0805K
CC1110: CC1110; QLP-36_UPDATE
CC1110-DEBUG: CC-DEBUG-PWR; CC-P05
FID1, FID2, FID3: FIDUCIAL; FIDUCIAL_1MM
IC1: 0915BM15A0001
J1: U.FL
JP1: M02-JST-2MM-SMT; JST-2-SMD
L1: 2.2 uH; L2825P
LED1: red; SML0603
LED2, LED5: blue; SML0603
LED3, LED4: green; SML0603
PWR: SW_SLIDE; SLIDE_SWITCH_SMD
R1: 2K; R0402
R2: 330; R0402
R3: 56kOhm ± 1%; R0402
R4, R9: R-US_R0402; R0402
R7, R11, R12, R13: 470 ohms; R0402
U1: MCP73831; 5PIN_SOT23
U3: BLE113-A
VREG: LM3671; SOT23-5
X1: 24MHz 8pF 10ppm -20C +70C; CTS_32X25
X3: MINI-USB-UX60-MB-5ST; UX60-MB-5ST

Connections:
DC: CC1110.16 (P2.2), CC1110-DEBUG.3 (DC)
DC_BLE: BLE113-DEBUG.3 (DC), U3.P2_2
DD: CC1110.15 (P2.1), CC1110-DEBUG.4 (DD)
DD_BLE: BLE113-DEBUG.4 (DD), U3.P2_1
GND: ALT.PWR.1, BLE113-DEBUG.1 (GND), C1.2, C2.2, C3.2, C4.2, C5.2, C6.2, C7.2, C8.2, C9.1, C10.2, C11.2, C12.2, C13.2, C14.2, CC1110.37 (GND), CC1110.38 (GND), CC1110.39 (GND), CC1110.40 (GND), CC1110-DEBUG.1 (GND), IC1.2 (GND), IC1.5 (GND), IC1.6 (GND), J1.P$1 (GND), J1.P$2 (GND), JP1.1 (2), LED2.C, LED3.C, LED4.C, LED5.C, R1.1, R3.1, U1.P$2 (VSS), U3.GND, U3.GND@2 (GND), U3.GND@3 (GND), U3.GND@4 (GND), U3.GND@5 (GND), U3.GND@6 (GND), U3.GND@7 (GND), U3.GND@8 (GND), U3.GND@9 (GND), U3.GND@10 (GND), VREG.2 (GND), X1.2 (GND), X1.4 (GND), X3.5
MISO: BLE113-DEBUG.10 (MISO), CC1110.32 (P1.7), CC1110-DEBUG.10 (MISO), U3.P0_2
MOSI: BLE113-DEBUG.8 (MOSI), CC1110.33 (P1.6), CC1110-DEBUG.8 (MOSI), U3.P0_3
unnamed: LED1.C, U1.P$1 (STAT)
unnamed: R1.2, U1.P$5 (PROG)
unnamed: LED1.A, R2.2
unnamed: CC1110.24 (RF-N), IC1.3 (BAL)
unnamed: CC1110.23 (RF-P), IC1.4 (BAL)
unnamed: J1.P$3 (SIGNAL), R4.1
unnamed: IC1.1 (UNBAL), R4.2, R9.1
unnamed: ANT1.1, R9.2
unnamed: CC1110.27 (RBIAS), R3.2
unnamed: L1.2, VREG.5 (SW)
unnamed: C9.2, CC1110.30 (DCOUPL)
unnamed: C6.1, CC1110.21 (XOSC1), X1.1 (X1)
unnamed: C5.1, CC1110.20 (XOSC2), X1.3 (X2)
unnamed: LED4.A, R7.1
unnamed: LED5.A, R11.1
unnamed: LED2.A, R12.1
unnamed: LED3.A, R13.1
unnamed: R12.2, U3.P0_1
unnamed: R13.2, U3.P0_0
P0_0: CC1110.5 (P0.0), R7.2
P0_1: CC1110.6 (P0.1), R11.2
RESET: BLE113-DEBUG.7 (RES), CC1110.31 (RESET), CC1110-DEBUG.7 (RES), U3.RESET
SCK: BLE113-DEBUG.6 (SCK), CC1110.34 (P1.5), CC1110-DEBUG.6 (SCK), U3.P0_5
SSN: BLE113-DEBUG.5 (SSN), CC1110.35 (P1.4), CC1110-DEBUG.5 (SSN), U3.P0_4
V+: C14.1, PWR.COM, VREG.1 (VIN), VREG.3 (EN)
VBAT: C3.1, JP1.2 (1), PWR.NC, U1.P$3 (VBAT)
VDD: BLE113-DEBUG.2 (3V3_SENS), C1.1, C4.1, C7.1, C8.1, C10.1, C11.1, C12.1, C13.1, CC1110.2 (DVDD), CC1110.10 (DVDD), CC1110.19 (AVDD), CC1110.22 (AVDD), CC1110.25 (AVDD), CC1110.26 (AVDD), CC1110.28 (GUARD), CC1110.29 (AVDD-DREG), CC1110-DEBUG.2 (3V3_SENS), L1.1, U3.AVDD, U3.DVDD, VREG.4 (FB)
VIN_USB: ALT.PWR.2, C2.1, R2.1, U1.P$4 (VDD), X3.1

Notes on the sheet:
LIPO Battery

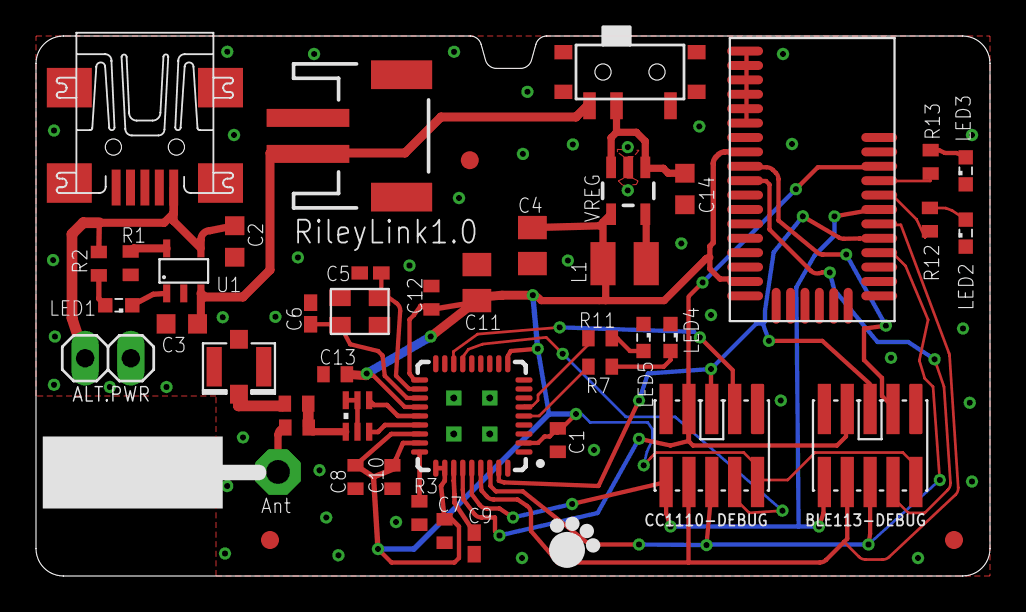
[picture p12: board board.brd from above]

Board: 2 copper layers, 53.0 x 30.0 mm, 46 parts (0 on the bottom side), 35 nets.

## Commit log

2015-05-06 Reconstructed v0.2
    [board.brd, board.sch]
2015-05-06 hardware dir
    [board.brd, board.sch]
2015-05-22 Adding materials list
    [board.sch, bom.csv]
2015-05-23 Update with battery, sparkfun notes
    [bom.csv]
2015-05-23 scale board pic down
2015-05-23 Adding 3d printer files
2015-05-23 Adding 3d printed case
2015-05-23 update case pic
2015-05-23 Fix coverter part number
    [board.brd, board.sch, bom.csv]
2015-05-23 Add slide switch part number, and inductor package size
    [bom.csv]
2015-05-23 Add price estimate list
    [prices.csv]
2015-06-08 Remove chip antenna, add fiducials, clean up labels, annotate RileyLink0.3
    [board.brd, board.sch]
2015-06-08 Rounded corners, align fiducials
    [board.brd, board.sch]
2015-06-08 update label: RileyLink0.6
    [board.brd]
2015-06-11 Fix bias resistor value
    [bom.csv]
2015-06-11 Update value of bias resistor
    [board.brd, board.sch]
2015-06-11 Update crystal value and part number
    [board.brd, board.sch, bom.csv]
2015-06-13 Add colors to leds, and switch 4.7uF cap from 0402 to 0603 package
    [board.brd, board.sch]
2015-06-16 Update C11 to 0805
    [board.brd, board.sch]
2015-06-17 Adjust trace per Jason's recommendation
    [board.brd]
2015-06-17 Update L1 part number
    [bom.csv]
2015-06-26 Adding cc-debugger connection illustration
    [board.brd, board.sch]
2015-07-23 Add illustration to show fitting components in case
2015-07-29 Show devices in rileylink list
2015-07-29 Track ble devices separate from records about how to interact with them
2015-07-31 display packet log. and add framework for supporting multiple rileylinks
2015-08-03 Add timer to reset rx
2015-08-09 Adding pumpID entry
2015-08-09 Keep pumpid textfield visible when keyboard brought up
2015-08-09 Filter out packets from other pumps
2015-08-10 Sending pump wakeup
2015-08-13 query and display pump model
2015-08-17 Show connecting state, and poll battery in pump chat ui
2015-08-25 Marked variables in minimed_rf as volatile as they are modified from within an interrupt
2015-09-09 Add bottom restrict for antenna performance
    [board.brd]
2015-09-12 Move antenna alignment guide to tplace layer
    [board.brd]
2015-09-12 Add diagram to show placement of reset button
    [board.brd]
2015-09-12 accidental undo
    [board.brd]
2015-09-12 move antenna wire silk to tPlace layer
    [board.brd]
2015-09-12 Update package for TPS63031
    [bom.csv]
2015-09-21 Update c11 to show it is an 0805 size part
    [bom.csv]
2015-09-21 Update size of C2 to 0603, so you can use same part for C2 and C3
    [bom.csv]
2015-10-06 Update parts for 24MHz in schematic and BOM
    [board.brd, board.sch, bom.csv]
2015-10-12 Update frequency for 12pF load capacitors for 24MHzw crystal
2015-10-13 Update loading cap specifications to 12pF
    [board.brd, board.sch, bom.csv]
2015-12-26 Adding ble113 firmware for communicating with subg_rfspy over spi
2015-12-28 Send 0x99 for polling command, expect command length prefix from client, and send spi data in chunks of 32
2016-01-01 Fix spi length arg. Not sure the arg is used, as it didn't seem to cause errors, but it was wrong regardless
2016-01-04 another spi rewrite. much better performance now
2016-01-24 Create RL-DK-BOM.csv
    The BOM for 1 RL board, with quantities. Import into Digi-Key by using DK BOM Manager.
    [RL-DK-BOM.csv]
2016-01-30 Prevent spi xfer when client writes new command, if client hasn't picked up existing data.
2016-01-31 Convert 100nF to 0.1uF since that's how they're sold
    [bom.csv]
2016-01-31 Block do_spi from being entered multiple times due to interrupts
2016-02-01 Add timer tick
2016-04-18 Fix decoupling cap; it was an error to have it so big. Also, the Digikey BOM had a mistake for its part number.
    [RL-DK-BOM.csv, board.brd, board.sch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]
2016-04-21 reduce amount of solder under cc1110, and label board 0.7p for production run
    [board.brd, board.sch]
2016-04-21 Fix description of 1.5uH inductor
    [RL-DK-BOM.csv]
2016-04-22 Map all parts to digikey part numbers, unify part names and descriptions.
    [RL-DK-BOM.csv, board.brd, board.sch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]
2016-04-22 Update placement marks to show part orientation
    [board.brd, board.sch]
2016-04-30 remove old price estimates
    [prices.csv]
2016-05-10 Remove tactile switch - no digikey equivalent exists
    [bom.csv, parts.csv]
2016-05-18 update blue led
2016-06-15 update board image
2016-07-23 Updated .stl files
    Added "bumpers" to support USB port to top and bottom and access hole for power switch to top (and also removed hole for battery wires).
    [case_bottom_edit.stl, case_top_edit.stl]
2016-09-23 clear output buffer for use as dummy data when receiving data over spi
2016-09-30 disable blue led as default, but allow it to be turned back on
2016-11-13 New layout for voltage regulator, add 2 pin header for alternate power.
    [board.brd, board.sch]
2016-12-03 Adding higher rated inductor
    [board.brd, board.sch, bom.csv]
2016-12-03 update label
    [board.brd]
2016-12-03 add pawprint
    [board.brd]
2016-12-03 update bom
    [bom.csv]
2017-01-04 Switch to buck-converter
    [board.brd, board.sch, bom.csv]
2017-01-04 update vreg part num
    [bom.csv]
2017-02-11 Update version to 1.0
    [board.brd]
2017-02-11 Add partnames to pcb, and update bom
    [board.brd, board.sch, bom.csv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]
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2017-05-09 Update oshpark link, and comment about EU pumps
2018-02-10 Only drive SPI while ble client connected
2018-05-23 Change led mode to off by default
2019-05-19 Update BOM with Digikey replacement parts.
    [bom.csv]
2019-05-19 Update parts list
    [parts.csv]
2019-06-07 Adding PDFs for schematic and board layouts

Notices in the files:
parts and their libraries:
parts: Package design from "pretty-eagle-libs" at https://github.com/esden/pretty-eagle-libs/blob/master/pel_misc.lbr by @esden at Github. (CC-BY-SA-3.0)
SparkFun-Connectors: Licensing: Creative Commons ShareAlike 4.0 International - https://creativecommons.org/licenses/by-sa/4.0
